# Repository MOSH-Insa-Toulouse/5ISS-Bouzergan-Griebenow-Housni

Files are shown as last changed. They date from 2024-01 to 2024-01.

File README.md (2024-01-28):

MOSH Gas Sensor
Kenza Bouzergan, Stig Griebenow, Lamiaa Housni

Our project revolves around the integration of a gas sensor, developed during a training period at AIME. Aligned with the objectives of the Innovative Smart Systems major, we undertook the entire process—from conception and creation in the AIME laboratory to schematic design, routing, wiring, programming, and addressing wireless communication and network aspects.

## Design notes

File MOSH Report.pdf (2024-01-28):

## MOSH Gas Sensor

Kenza Bouzergan, Stig Griebenow, Lamiaa Housni

Our project revolves around the integration of a gas sensor, developed during a training period at AIME. Aligned with the objectives of the Innovative Smart Systems major, we undertook the entire process—from conception and creation in the AIME laboratory to schematic design, routing, wiring, programming, and addressing wireless communication and network aspects.

This project serves as an overall test of our proficiency in key areas, including network knowledge, programming skills, and electronics expertise. The core objective is to send sensor data over a LoRa network to a dashboard for visualization and analysis. In this report, we will succinctly outline each step taken, highlighting the challenges addressed and the refined skills acquired to achieve our final results.

## Integration of the Lora Network

To initiate our project, we initially attempted to link an Arduino with the Lora network. This was accomplished using a Microchip-manufactured RN2483 chip, a module that is capable of Lora network communication. Given that this chip is equipped with only small connectors, it was necessary to solder the component onto a board that has larger connectors to facilitate communication with the Arduino.

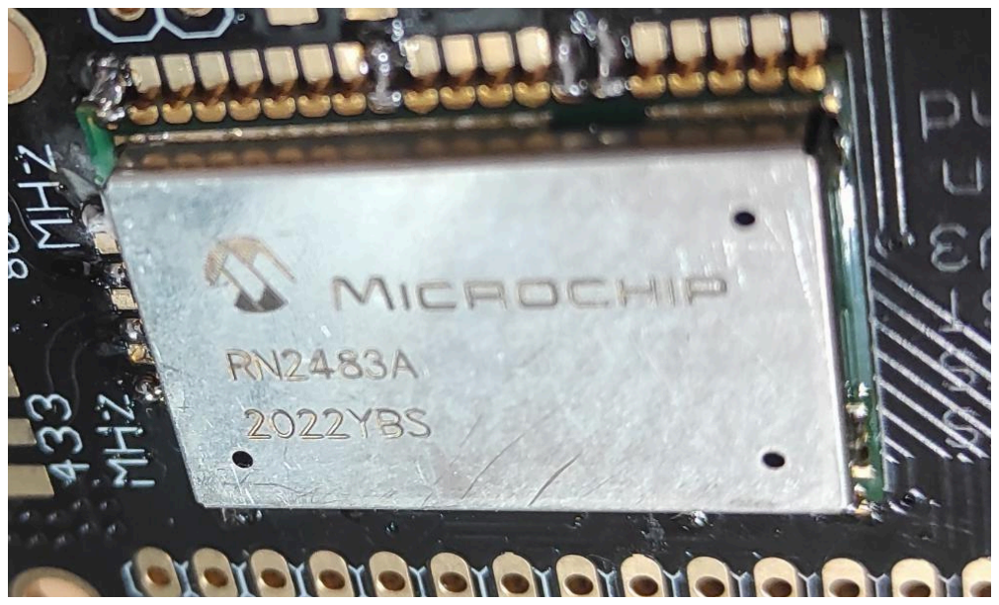
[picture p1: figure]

RN2483 Module soldered on the board

Following this step, we successfully connected our Arduino to the INSA's Lora network. This connection allowed us to integrate our device into the network infrastructure, enabling communication and data exchange using the established Lora technology.

## Integration of the MQ-3B gas sensor

Once the connection with the gateway was successfully established, our next goal was to transmit data to it. This step is crucial for retrieving and displaying data on a dashboard. For our prototype, we chose the MQ-3B gas sensor, known for its capability to detect gas concentrations, and integrated it with our Arduino system. This sensor was ideal for our application's requirements. The final setup included the Arduino board, the RN2483 module for LoRa communication, and the MQ-3B sensor. This assembly created a functional circuit capable of detecting and wirelessly transmitting gas concentration data to the gateway.

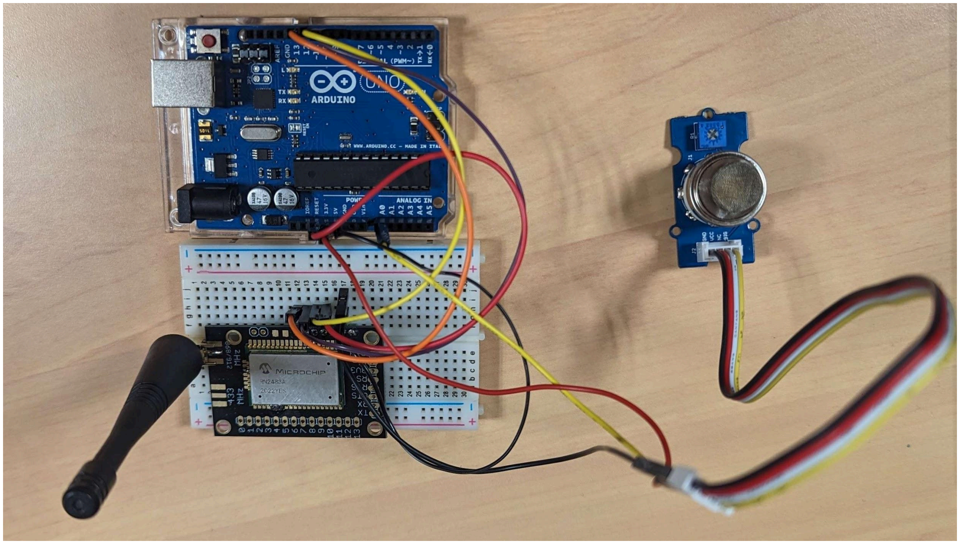
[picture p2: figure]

Montage of the circuit

## Development of a node-red application

Node-RED is a flow editor that operates within a web browser, facilitating the easy connection of different data flows.

In our application, we used Node-RED's MQTT subscribe block to receive data from ChirpStack. This data is initially encoded in base64 by ChirpStack. To handle this, we piped the incoming data into a JavaScript function block specifically designed to decode the base64 format. Once decoded, this data is then routed to a dashboard block within Node-RED. This final step allows us to visually represent and monitor the data in a clear and accessible manner on the dashboard.

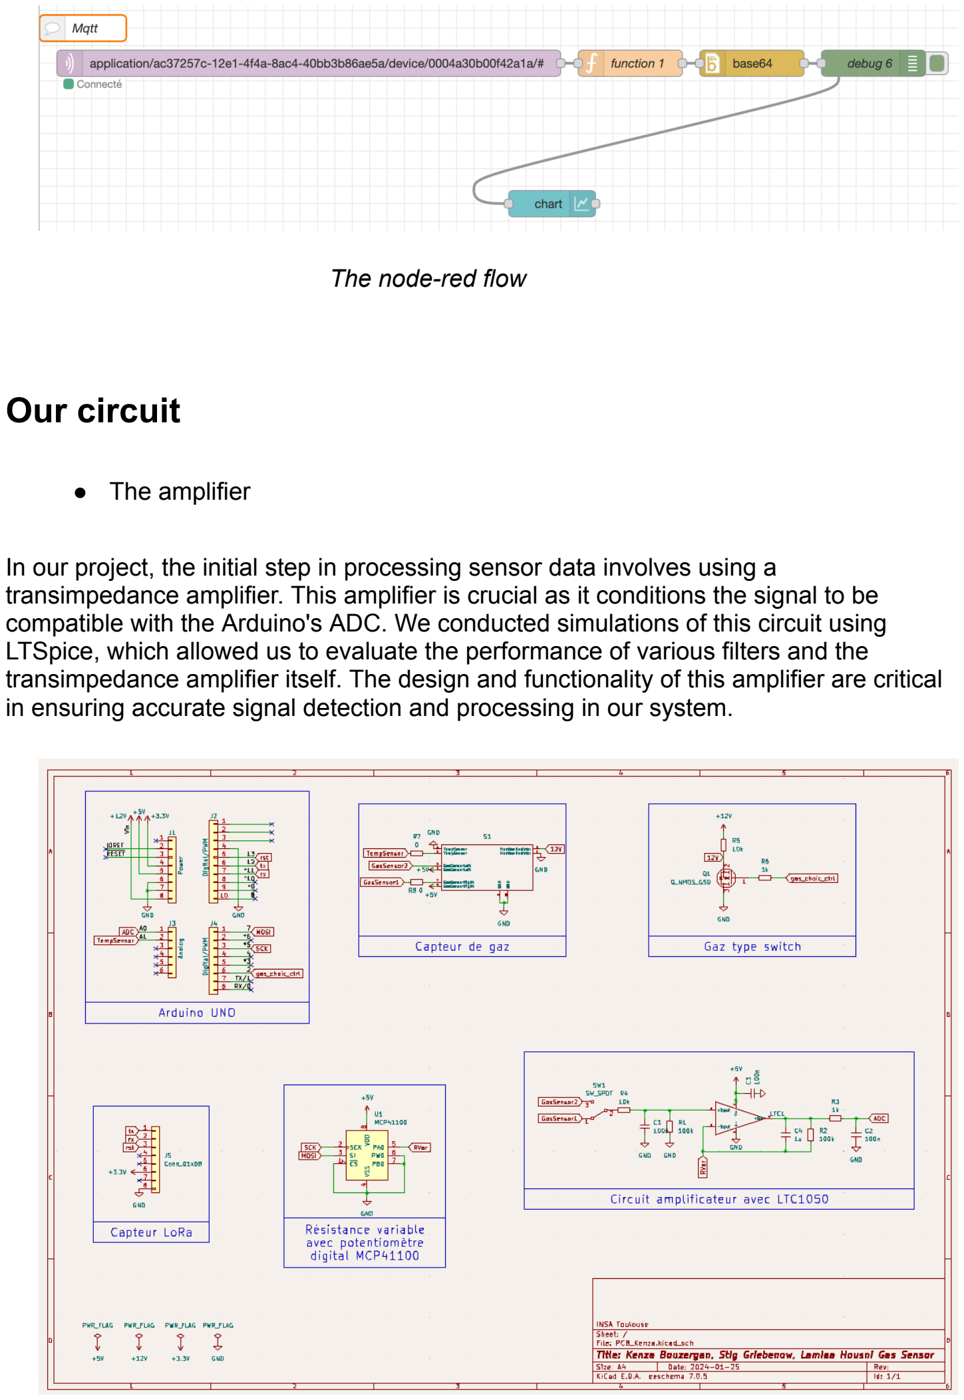
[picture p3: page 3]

The node-red flow

## Our circuit

- The amplifier

In our project, the initial step in processing sensor data involves using a transimpedance amplifier. This amplifier is crucial as it conditions the signal to be compatible with the Arduino's ADC. We conducted simulations of this circuit using LTSpice, which allowed us to evaluate the performance of various filters and the transimpedance amplifier itself. The design and functionality of this amplifier are critical in ensuring accurate signal detection and processing in our system.

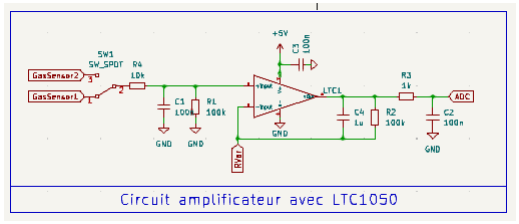
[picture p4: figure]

Our amplifier

- The digital potentiometer

In our setup, we integrated a digital potentiometer to function as a variable resistor, selecting the MCP41100 model. This particular component is powered by a 5V supply and is controlled by the Arduino through the SPI. The use of a digital potentiometer like the MCP41100 allows for precise and programmable control over resistance.

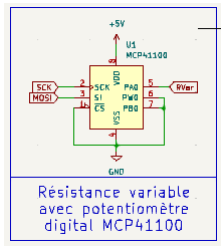
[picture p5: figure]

Montage for the digital potentiometer

- Sensor connections

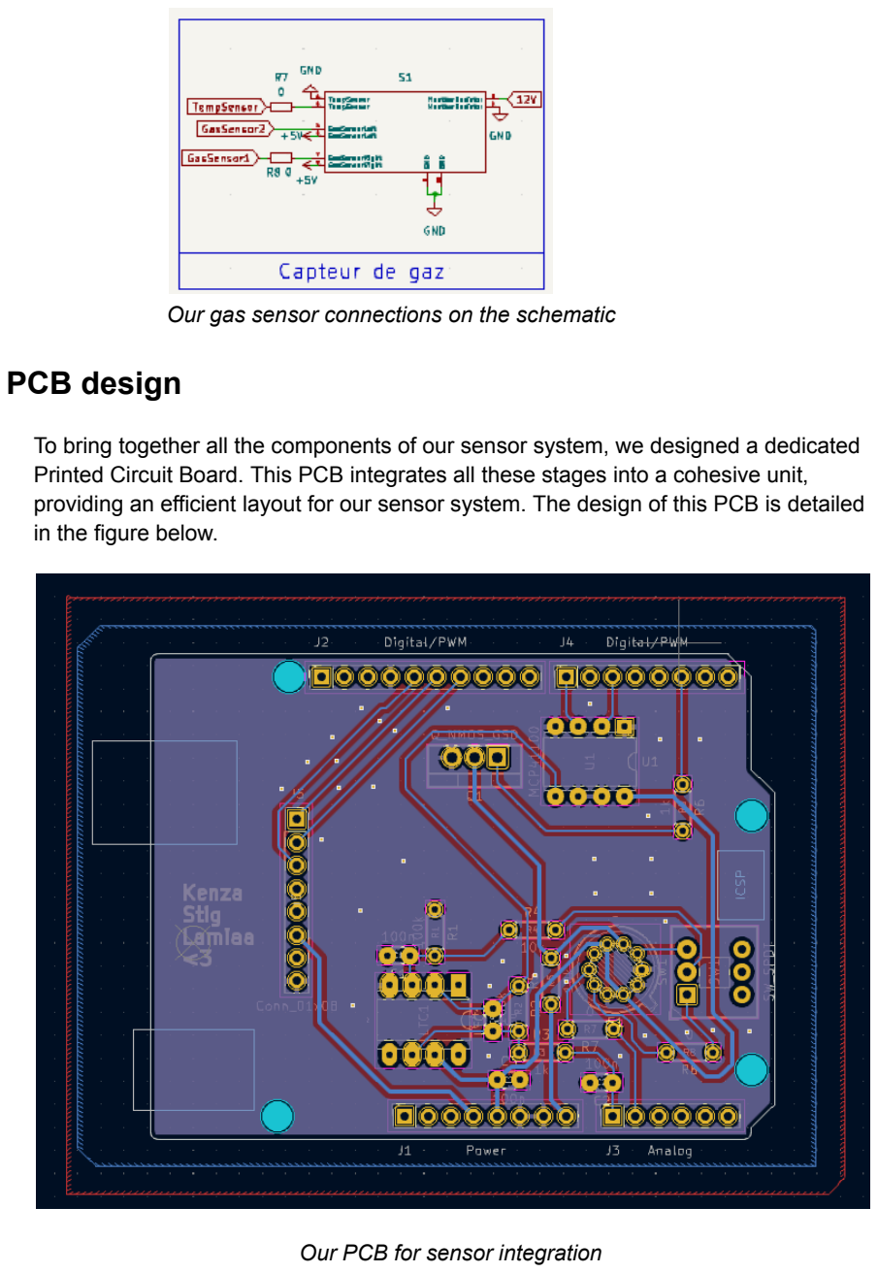
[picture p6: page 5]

Our gas sensor connections on the schematic

## PCB design

To bring together all the components of our sensor system, we designed a dedicated Printed Circuit Board. This PCB integrates all these stages into a cohesive unit, providing an efficient layout for our sensor system. The design of this PCB is detailed in the figure below.

Our PCB for sensor integration

## Future work

Moving forward with our project, the next crucial steps would include manufacturing the designed PCB, soldering all the components, and testing the electrical circuits. Additionally, we need to develop software for controlling the heating resistor and potentiometer. We would also tes the sensor's reactivity to NH3 and C2H6O, followed by a test to evaluate the LoRa data transmission and the integration with the Node-RED application. This approach will ensure the realibility of our system in real-world scenarios.

## Conclusion

This project offered a thorough initiation into the world of sensor technology, covering all stages from the initial creation to the final application of displaying data on dashboards. It made us improve our skills in various domains such as LoRa communication, Node-RED application creation, and PCB design.

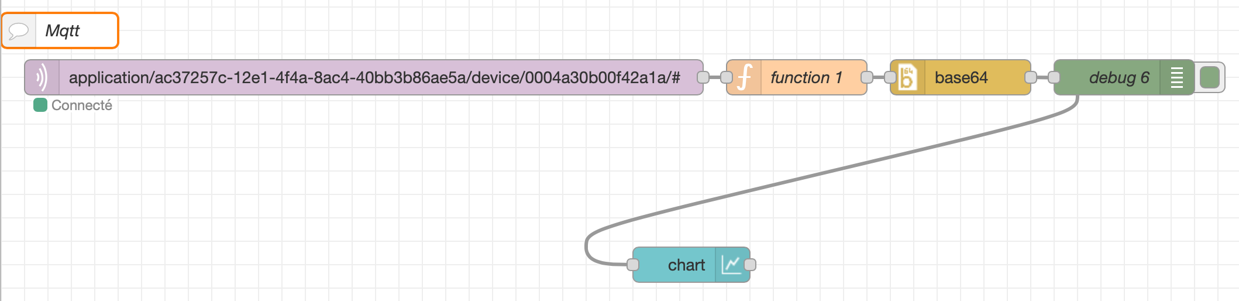
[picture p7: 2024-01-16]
NodeRED/Node red flow.png

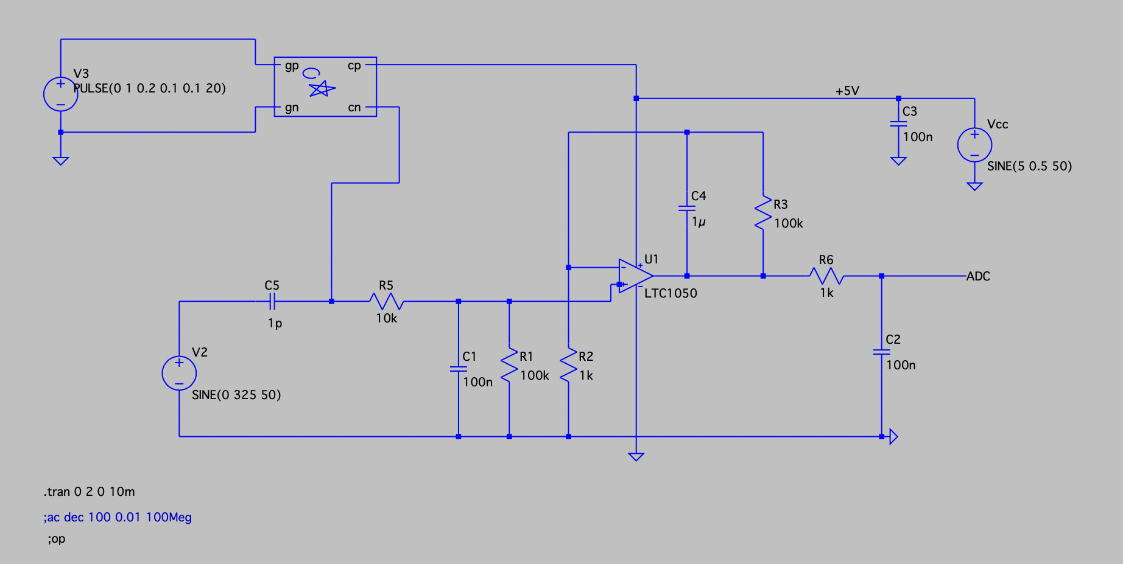
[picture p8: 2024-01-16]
LTSpice files/Amplifier.png

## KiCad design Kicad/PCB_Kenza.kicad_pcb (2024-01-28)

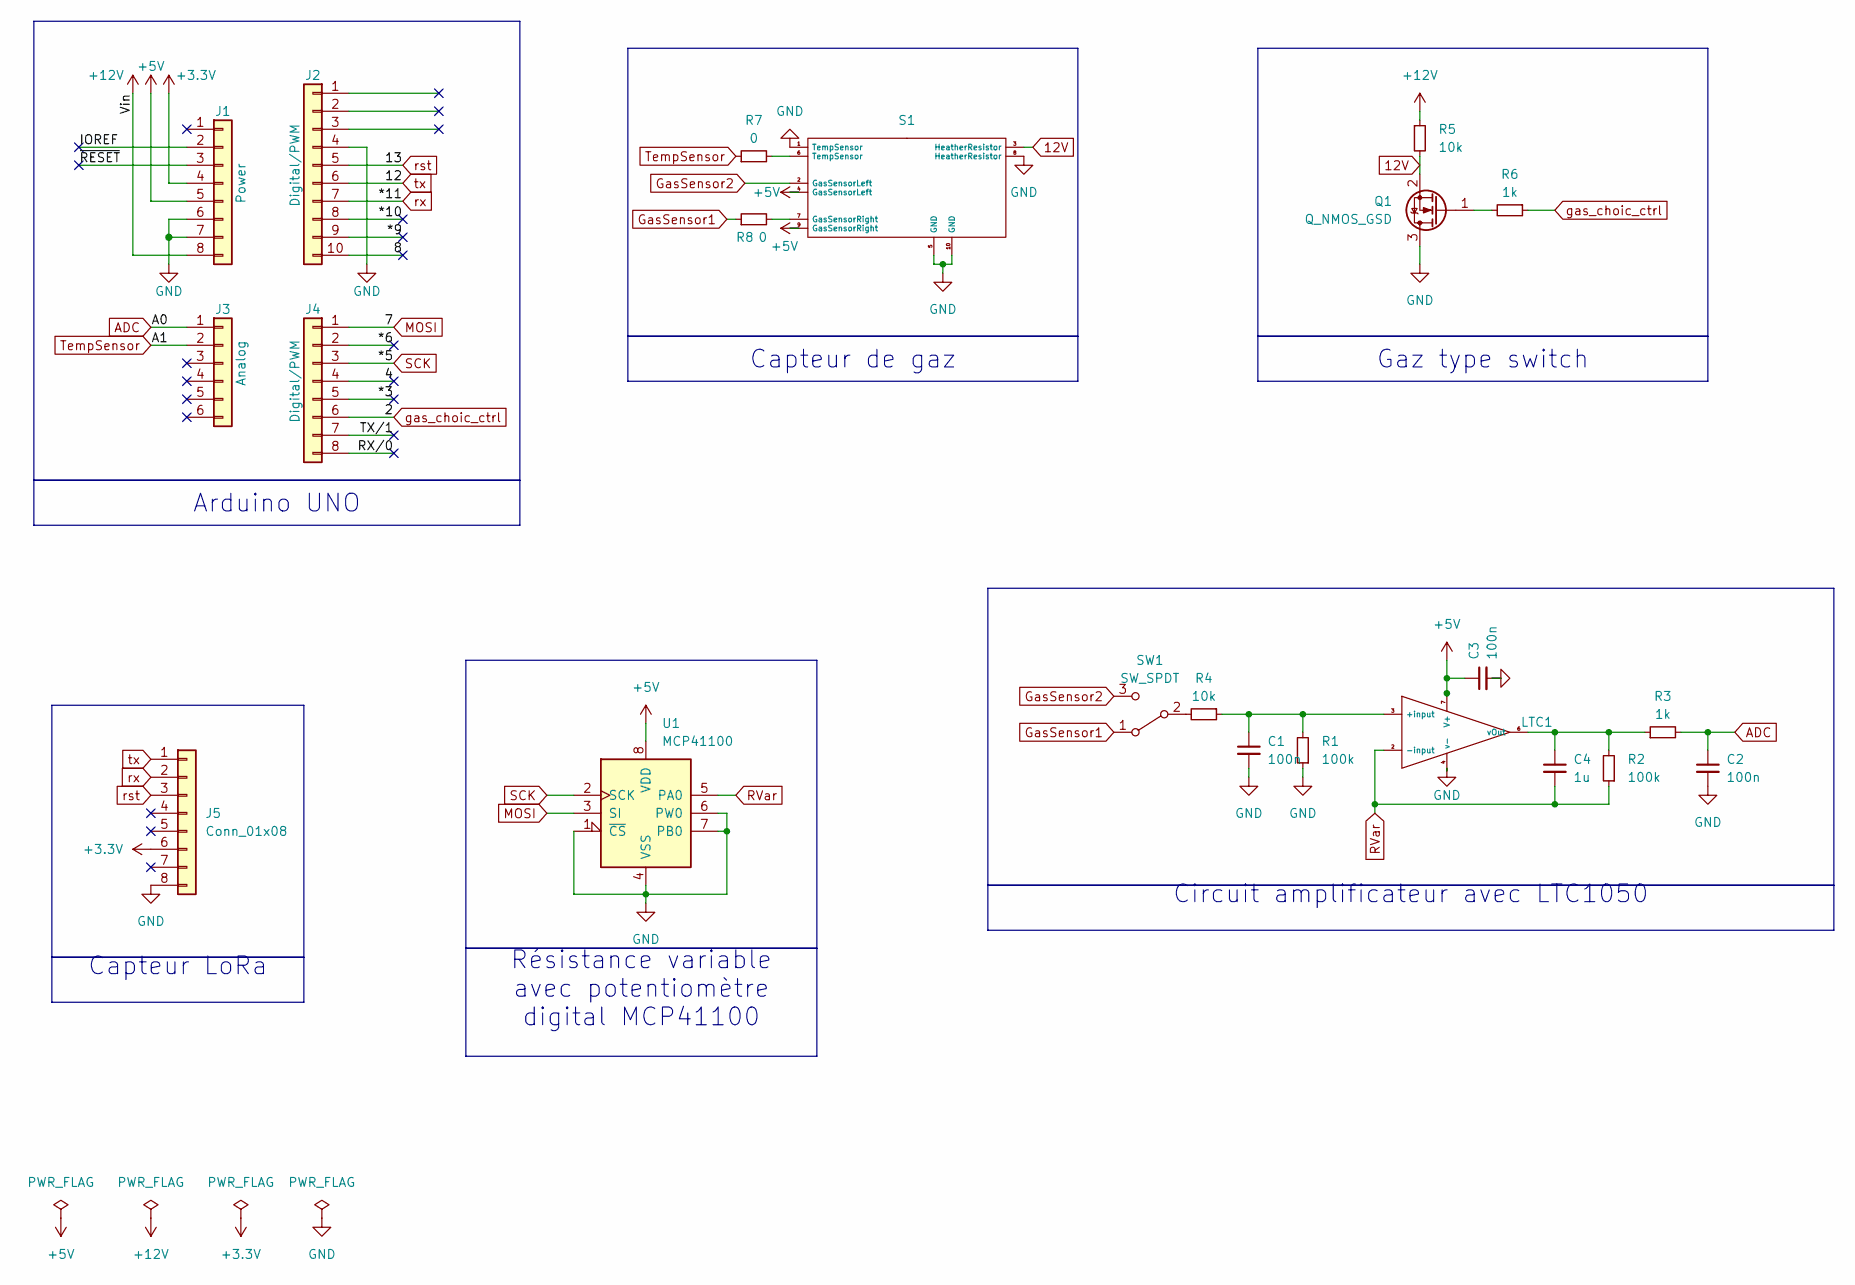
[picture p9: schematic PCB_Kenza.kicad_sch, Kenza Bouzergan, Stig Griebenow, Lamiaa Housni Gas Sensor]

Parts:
C1, C2, C3: 100n; C_Disc_D3.0mm_W1.6mm_P2.50mm
C4: 1u; C_Disc_D3.0mm_W1.6mm_P2.50mm
J1: Power; PinSocket_1x08_P2.54mm_Vertical
J2: Digital/PWM; PinSocket_1x10_P2.54mm_Vertical
J3: Analog; PinSocket_1x06_P2.54mm_Vertical
J4: Digital/PWM; PinSocket_1x08_P2.54mm_Vertical
J5: Conn_01x08; PinSocket_1x08_P2.54mm_Vertical
LTC1: DIP-8_W7.62mm_LongPads
Q1: Q_NMOS_GSD; TO-220-3_Vertical
R1, R2: 100k; R_Axial_DIN0204_L3.6mm_D1.6mm_P5.08mm_Horizontal
R3, R6: 1k; R_Axial_DIN0204_L3.6mm_D1.6mm_P5.08mm_Horizontal
R4, R5: 10k; R_Axial_DIN0204_L3.6mm_D1.6mm_P5.08mm_Horizontal
R7, R8: 0; R_Axial_DIN0204_L3.6mm_D1.6mm_P5.08mm_Horizontal
S1: TO-5-10_Window
SW1: SW_SPDT; SW_Push_2P2T_Toggle_CK_PVA2xxH2xxxxxxV2
U1: MCP41100; DIP-8_W7.62mm

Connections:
12V: Q1.2 (S), R5.2, S1.3 (HeatherResistor)
+3.3V: J1.4, J5.6
+5V: C3.1, J1.5, LTC1.7 (V+), S1.4 (GasSensorLeft), S1.9 (GasSensorRight), U1.8 (VDD)
+12V: J1.8, R5.1
/4: J4.4
/8: J2.10
/*3: J4.5
/*6: J4.2
/*9: J2.9
/*10: J2.8
/IOREF: J1.2
/RX/0: J4.8
/TX/1: J4.7
/~RESET: J1.3
ADC: C2.1, J3.1, R3.2
GND: C1.2, C2.2, C3.2, J1.6, J1.7, J2.4, J5.8, LTC1.4 (v-), Q1.3 (D), R1.1, S1.1 (TempSensor), S1.5 (GND), S1.8 (HeatherResistor), S1.10 (GND), U1.1 (~CS), U1.4 (VSS), U1.6 (PW0), U1.7 (PB0)
GasSensor1: R8.1, SW1.1 (A)
GasSensor2: S1.2 (GasSensorLeft), SW1.3 (C)
MOSI: J4.1, U1.3 (SI)
unnamed: C1.1, LTC1.3 (+input), R1.2, R4.1
unnamed: C4.1, LTC1.6 (vOut), R2.2, R3.1
unnamed: Q1.1 (G), R6.2
unnamed: R7.2, S1.6 (TempSensor)
unnamed: R8.2, S1.7 (GasSensorRight)
unnamed: R4.2, SW1.2 (B)
RVar: C4.2, LTC1.2 (-input), R2.1, U1.5 (PA0)
SCK: J4.3, U1.2 (SCK)
TempSensor: J3.2, R7.1
gas_choic_ctrl: J4.6, R6.1
rst: J2.5, J5.3
rx: J2.7, J5.2
tx: J2.6, J5.1

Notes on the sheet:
Capteur de gaz
Circuit amplificateur avec LTC1050
Capteur LoRa
Résistance variable avec potentiomètre digital MCP41100
Arduino UNO
Gaz type switch

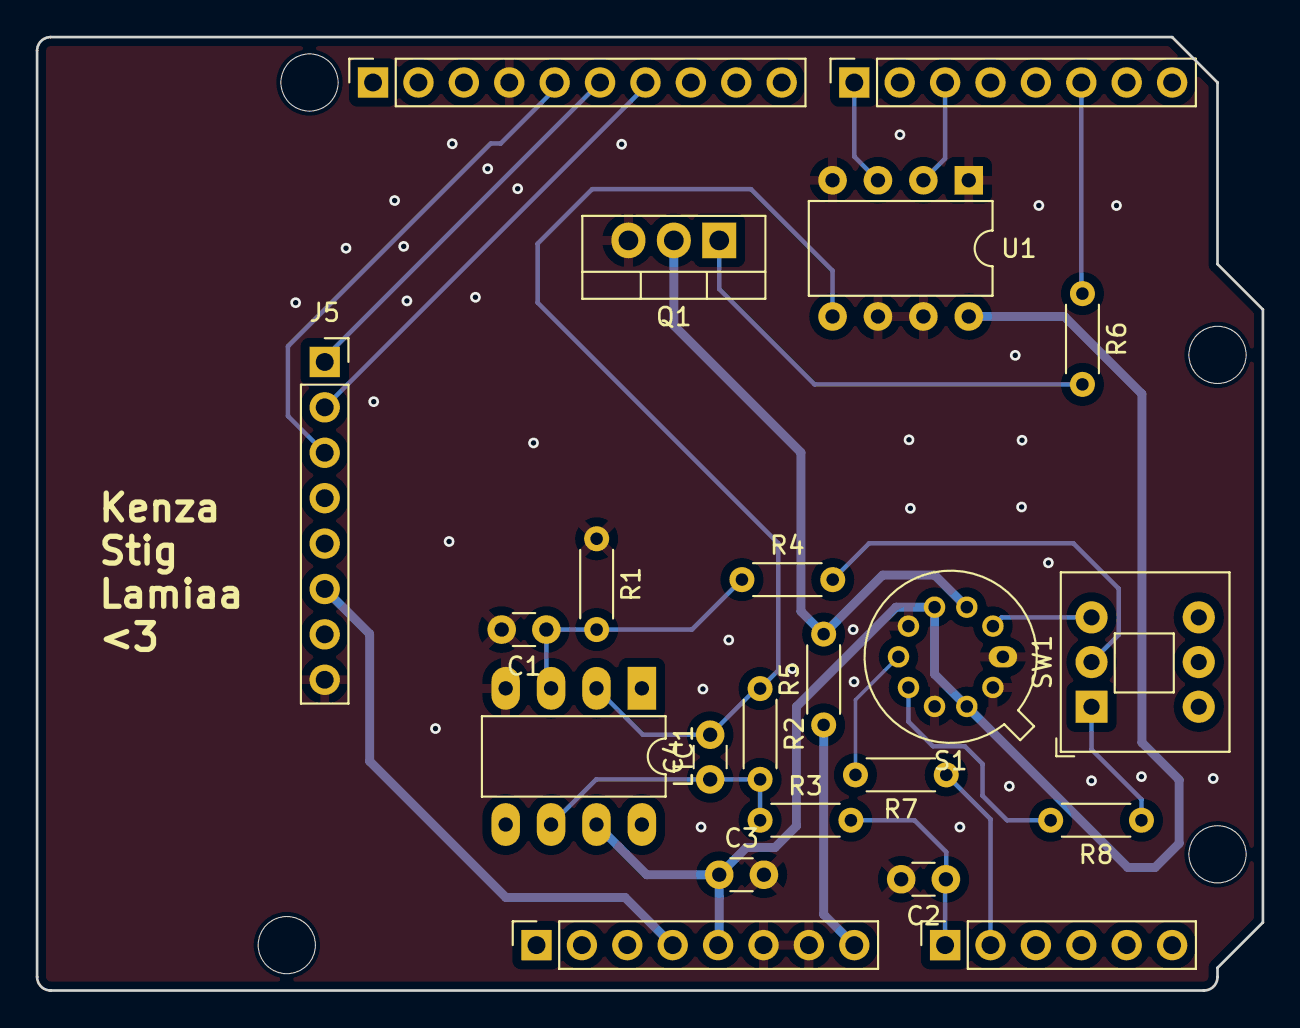
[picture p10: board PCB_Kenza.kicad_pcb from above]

Board: 2 copper layers, 68.6 x 53.3 mm, 26 parts (0 on the bottom side), 22 nets.

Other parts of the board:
MH1, MH2, MH3, MH4: MountingHole_3.2mm

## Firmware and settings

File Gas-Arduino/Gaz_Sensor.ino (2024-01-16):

/*
 * Author: JP Meijers
 * Date: 2016-02-07
 * Previous filename: TTN-Mapper-TTNEnschede-V1
 *
 * This program is meant to be used with an Arduino UNO or NANO, conencted to an RNxx3 radio module.
 * It will most likely also work on other compatible Arduino or Arduino compatible boards, like The Things Uno, but might need some slight modifications.
 *
 * Transmit a one byte packet via TTN. This happens as fast as possible, while still keeping to
 * the 1% duty cycle rules enforced by the RN2483's built in LoRaWAN stack. Even though this is
 * allowed by the radio regulations of the 868MHz band, the fair use policy of TTN may prohibit this.
 *
 * CHECK THE RULES BEFORE USING THIS PROGRAM!
 *
 * CHANGE ADDRESS!
 * Change the device address, network (session) key, and app (session) key to the values
 * that are registered via the TTN dashboard.
 * The appropriate line is "myLora.initABP(XXX);" or "myLora.initOTAA(XXX);"
 * When using ABP, it is advised to enable "relax frame count".
 *
 * Connect the RN2xx3 as follows:
 * RN2xx3 -- Arduino
 * Uart TX -- 10
 * Uart RX -- 11
 * Reset -- 12
 * Vcc -- 3.3V
 * Gnd -- Gnd
 *
 * If you use an Arduino with a free hardware serial port, you can replace
 * the line "rn2xx3 myLora(mySerial);"
 * with     "rn2xx3 myLora(SerialX);"
 * where the parameter is the serial port the RN2xx3 is connected to.
 * Remember that the serial port should be initialised before calling initTTN().
 * For best performance the serial port should be set to 57600 baud, which is impossible with a software serial port.
 * If you use 57600 baud, you can remove the line "myLora.autobaud();".
 *
 */
#include <rn2xx3.h>
#include <SoftwareSerial.h>

SoftwareSerial mySerial(10, 11); // RX, TX

//create an instance of the rn2xx3 library,
//giving the software serial as port to use
rn2xx3 myLora(mySerial);

//Gas Sensor Pin
int gasPin = 0;

// the setup routine runs once when you press reset:
void setup()
{
  //output LED pin
  pinMode(13, OUTPUT);
  led_on();

  // Open serial communications and wait for port to open:
  Serial.begin(9600); //serial port to computer
  mySerial.begin(57600); //serial port to radio
  Serial.println("Startup");

  initialize_radio();

  //transmit a startup message
  myLora.tx("TTN Mapper on TTN Enschede node");

  led_off();

  //setup analog pin
  analogReference(INTERNAL);

  delay(2000);
}

void initialize_radio()
{
  //reset rn2483
  pinMode(12, OUTPUT);
  digitalWrite(12, LOW);
  delay(500);
  digitalWrite(12, HIGH);

  delay(100); //wait for the RN2xx3's startup message
  mySerial.flush();

  //Autobaud the rn2483 module to 9600. The default would otherwise be 57600.
  myLora.autobaud();

  //check communication with radio
  String hweui = myLora.hweui();
  while(hweui.length() != 16)
  {
    Serial.println("Communication with RN2xx3 unsuccessful. Power cycle the board.");
    Serial.println(hweui);
    delay(10000);
    hweui = myLora.hweui();
  }

  //print out the HWEUI so that we can register it via ttnctl
  Serial.println("When using OTAA, register this DevEUI: ");
  Serial.println(myLora.hweui());
  Serial.println("RN2xx3 firmware version:");
  Serial.println(myLora.sysver());

  //configure your keys and join the network
  Serial.println("Trying to join TTN");
  bool join_result = false;


  /*
   * ABP: initABP(String addr, String AppSKey, String NwkSKey);
   * Paste the example code from the TTN console here:
   */
//  const char *devAddr = "02017201";
//  const char *nwkSKey = "AE17E567AECC8787F749A62F5541D522";
//  const char *appSKey = "8D7FFEF938589D95AAD928C2E2E7E48F";

/*Mon application sur TTN*/
//DEVICE 1
//  const char *devAddr = "26011444"; //26011444
//  const char *nwkSKey = "861B6A0F4279158C8309CA7C42BB48A1"; //861B6A0F4279158C8309CA7C42BB48A1
//  const char *appSKey = "4B3C84D3BECA32428600B7EC59698FCB"; //4B3C84D3BECA32428600B7EC59698FCB
//DEVICE 2
 //const char *devAddr = "26011051"; 
 //const char *nwkSKey = "AE05D00A33B5DFD49CBC450626149562"; 
 //const char *appSKey = "8630B16147DEF0319BFA52CDCD7F4E4E"; 



  //join_result = myLora.initABP(devAddr, appSKey, nwkSKey);

  /*
   * OTAA: initOTAA(String AppEUI, String AppKey);
   * If you are using OTAA, paste the example code from the TTN console here:
   */
   //TODO: Change here:
  const char *appEui = "88098b214b13ecfa";
  const char *appKey = "59c152b759c506993d2f227edaa43707";

  join_result = myLora.initOTAA(appEui, appKey);


  while(!join_result)
  {
    Serial.println("Unable to join. Are your keys correct, and do you have TTN coverage?");
    delay(60000); //delay a minute before retry
    join_result = myLora.init();
  }
  Serial.println("Successfully joined TTN");

}

// the loop routine runs over and over again forever:
void loop()
{
    led_on();

    //get gas sensor data
    float gas = analogRead(gasPin);
    //print gas value
    Serial.println(gas);


    Serial.println("TXing gas data!");
    myLora.tx(String(gas)); //one byte, blocking function

    led_off();
    delay(10000);
}

void led_on()
{
  digitalWrite(13, 1);
}

void led_off()
{
  digitalWrite(13, 0);
}

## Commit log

2024-01-16 Added arduino code
2024-01-28 Added Kicad files
    [PCB_Kenza.kicad_pcb, PCB_Kenza.kicad_sch]
